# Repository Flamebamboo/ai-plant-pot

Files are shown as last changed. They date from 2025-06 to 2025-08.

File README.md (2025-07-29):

# SmartPlanter aka PixPlanter

This project is an emotive smart planter that plays an animation through its OLED screen depending on the conditions from the soil moisture, temperature & humidity sensors. It's also designed for portability with a 2000 MAH lipo battery and easy battery charging with USB type C from the ESP32 C6 from xiao. With this microcontroller it supports HomeKit and battery charging built it which i'm really excited about. The CAD design of this planter contains 2 seprate compartments. The inner pot and the outer pot. The inner pot has a snap fit design and drainage holes for water to safely exit throughout the pot. I will add an safety precautious by adding waterproof silicone for the 3d printed parts just in case if there will be leaks that can cause danger to the electronics on the housing of the outer case.

The reason I built this project is because I want my baby Monstera plant to be healthy on my desk! and it would also be a great addition as decoration too!

### Additionaly I've made some short vlogs on my Youtube channel and my brand new Instagram account
https://youtube.com/shorts/UrM3IPHNWJw?si=KoA7QMxdPpVGsMg
I'm definitely planning to create long form yt vid for this project when it's fully completed :)

> **⚠️ Warning:** I will be writing the firmware when the MCU arrive and I'm planning to create a Swift or React Native app for this smart planter to control and customise the planter features! :)) .
> 
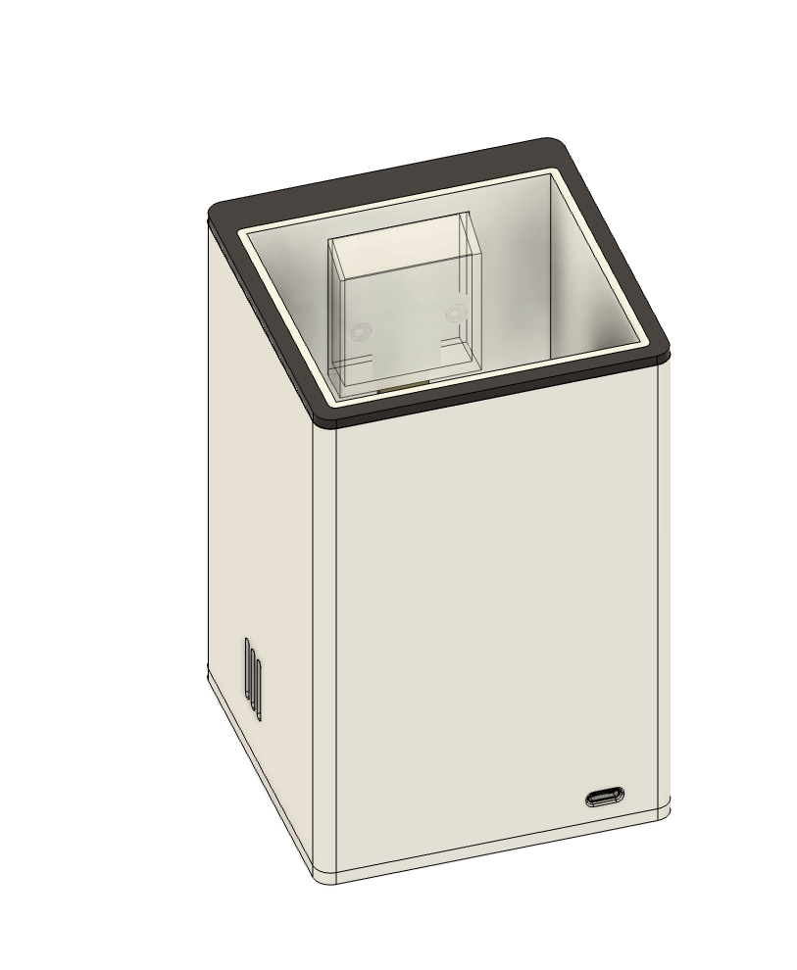
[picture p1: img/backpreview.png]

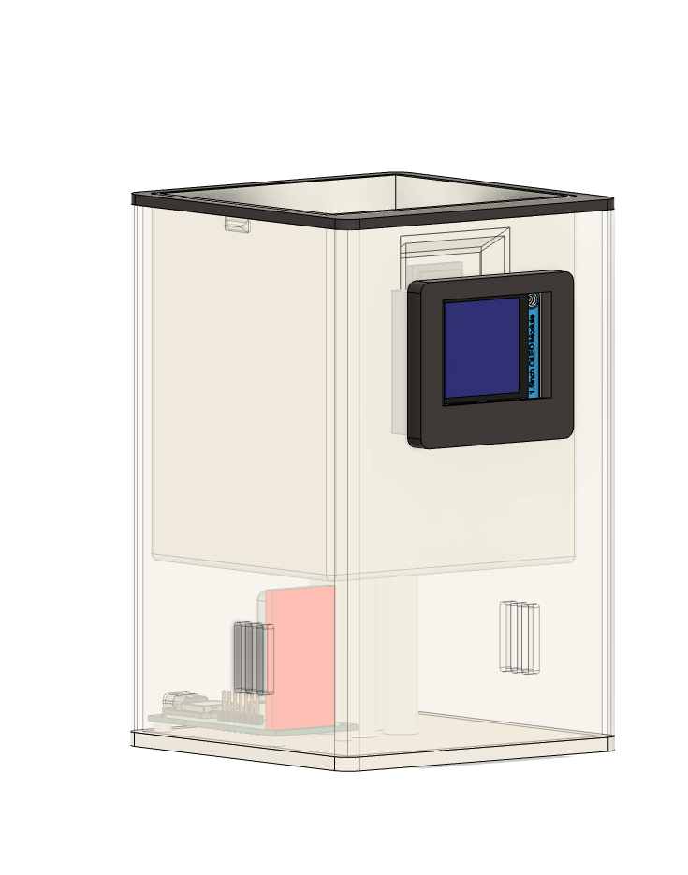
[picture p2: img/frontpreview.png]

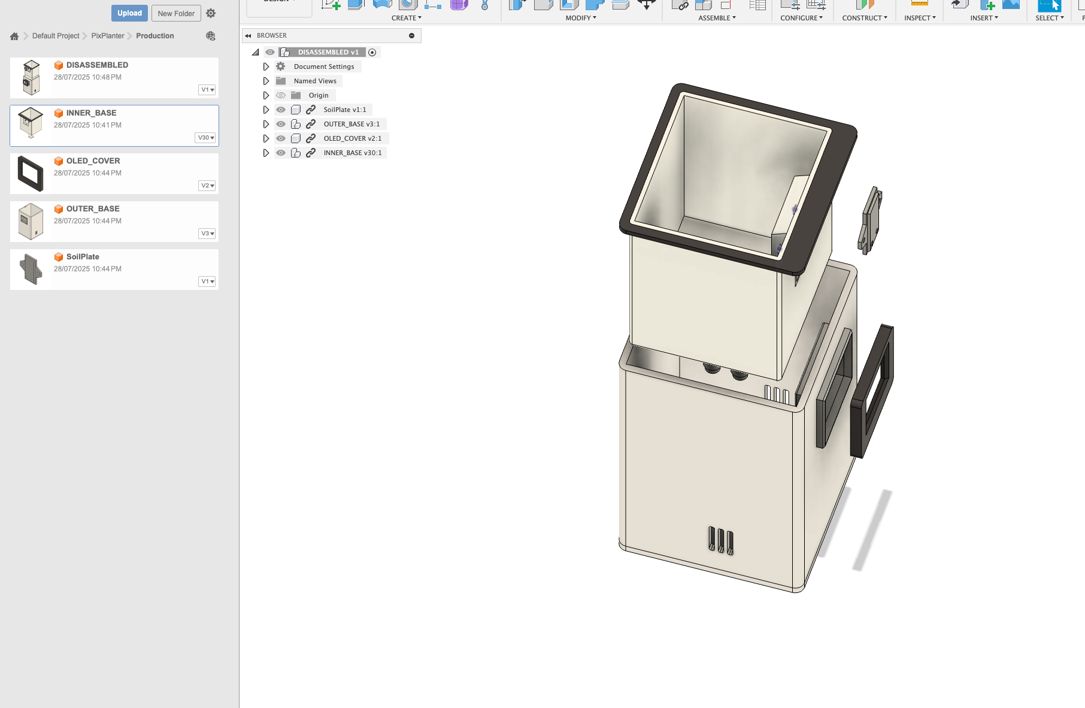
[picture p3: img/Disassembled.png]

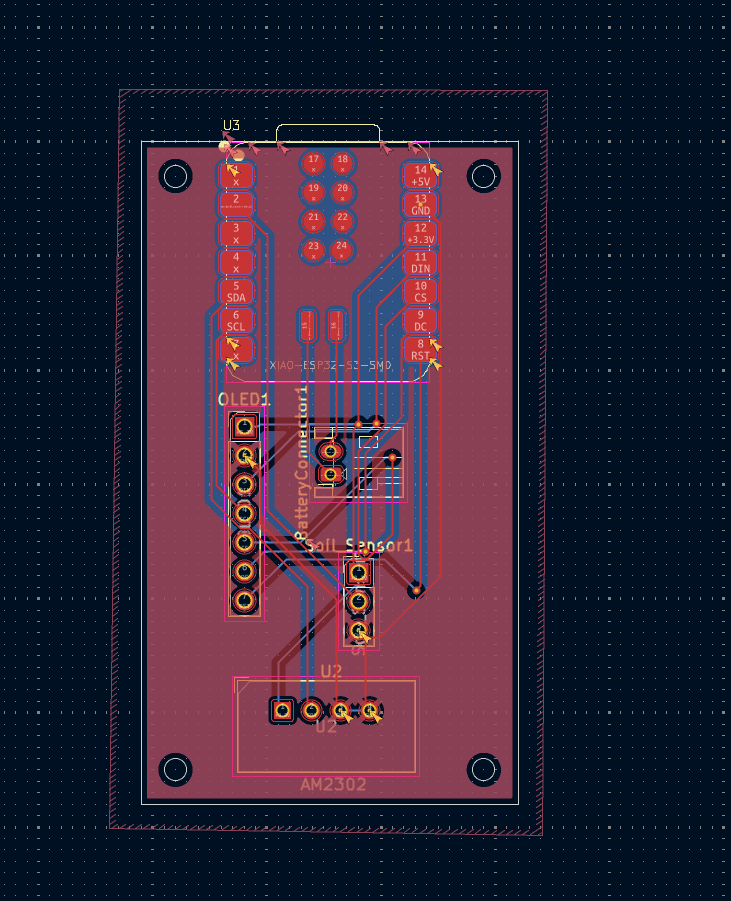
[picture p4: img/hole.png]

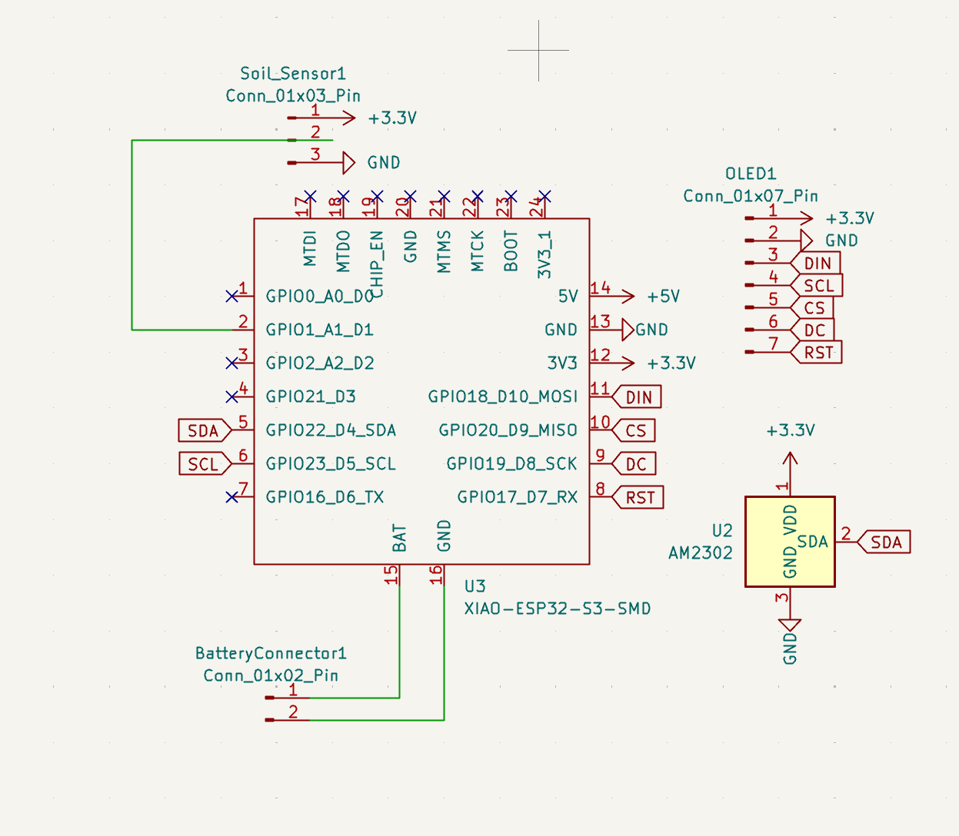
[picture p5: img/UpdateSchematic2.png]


## Bill of Materials (BOM)

| Component | Link | Price (USD) |
| --- | --- | --- |
| XIAO ESP32 C6 | [AliExpress](https://www.aliexpress.com/item/3256807155424151.html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) | $14.23 |
| 1.5 inch OLED display | [Waveshare](https://www.waveshare.com/product/displays/oled/oled-3/1.5inch-rgb-oled-module.html) | $16.59 |
| LIPO Battery 3.7V 2000mAH | [AliExpress](https://www.aliexpress.com/item/3256808031709894.html) | $3.86 |
| DHT22 Temperature and Humidity Sensor | [AliExpress](https://www.aliexpress.com/item/2251832573586959.html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) | $1.89 |
| Soil Sensor | [DigiKey](https://www.digikey.my/en/products/detail/adafruit-industries-llc/4026/9745252) | $7.50 |
| M2 × 8mm Screws | [AliExpress](https://www.aliexpress.com/item/2255800888609493.html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) | $1.59 |
| M2.6 × 4mm Screws | [AliExpress](https://www.aliexpress.com/item/2255800795894953.html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,scm-url:1007.22922.271278.0,pvid:9d1f35b8-b4ad-40c0-801f-28061212913c,tpp_buckets:668%232846%238115%232000&pdp_ext_f=%7B%22order%22%3A%222844%22%2C%22eval%22%3A%221%22%2C%22sceneId%22%3A%2212922%22%7D&pdp_npi=4%40dis%21USD%211.15%211.15%21%21%211.15%211.15%21%40214100f417536751956683208eb980%2110000013191635027%21rec%21US%216176438218%21X&spm=a2g0o.store_pc_home.smartLeaderboard_1182734993.4000982209705) | $1.29 |
| 2.54mm Pin Header Vertical (Soil moisture 2 pin) | [AliExpress](https://www.aliexpress.us/item/2255801012106911.html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) | $1.28 |
| 2.54mm Pin Header Vertical (OLED 7 pin) | [AliExpress](https://www.aliexpress.us/item/2255801012106911.html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) | $1.46 |
| JST PH 2.0mm Male Female Plug Jack Connector Cable 20 cm | [AliExpress](https://www.aliexpress.us/item/3256803204628036.html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) | $1.74 |
| **Total** | | **$51.43**  |

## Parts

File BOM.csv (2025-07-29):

Reference | Qty | Value | Footprint | Description | Link | Price
XIAO_ESP32_C6 | 1 | XIAO-ESP32-C6 | Library:XIAO-ESP32C6-SMD | XIAO ESP32 C6 | https://www.aliexpress.com/item/3256807155424151.html | 14.23
OLED_1.5IN | 1 | 1.5inch_RGB_OLED | Module:1.5inch_RGB_OLED | 1.5 inch OLED display | https://www.waveshare.com/product/displays/oled/oled-3/1.5inch-rgb-oled-module.html | 16.59
LIPO_BATT_2000mAh | 1 | LIPO_3.7V_2000mAh | Battery:LiPo_3.7V_2000mAh | LIPO Battery 3.7V 2000mAH | https://www.aliexpress.com/item/3256808031709894.html | 3.86
DHT22_AM2302 | 1 | AM2302 | Sensor:ASAIR_AM2302_P2.54mm_Vertical | DHT22 Temperature and Humidity Sensor | https://www.aliexpress.com/item/2251832573586959.html | 1.89
SOIL_SENSOR | 1 | Soil_Moisture_Sensor | Sensor:Soil_Moisture_3-Pin | Soil Sensor | https://www.digikey.my/en/products/detail/adafruit-industries-llc/4026/9745252 | 7.50
SCREW_M2_8MM | 1 | M2×8mm_Screw | Hardware:M2x8mm | M2 × 8mm Screws | https://www.aliexpress.com/item/2255800888609493.html | 1.59
SCREW_M2.6_4MM | 1 | M2.6×4mm_Screw | Hardware:M2.6x4mm | M2.6 × 4mm Screws | https://www.aliexpress.com/item/2255800795894953.html | 1.29
HDR_2PIN | 1 | PinHeader_1x02_P2.54mm | Connector_PinHeader_2.54mm:PinHeader_1x02_P2.54mm_Vertical | 2.54mm Pin Header Vertical (Soil moisture 2 pin) | https://www.aliexpress.us/item/2255801012106911.html | 1.28
HDR_7PIN | 1 | PinHeader_1x07_P2.54mm | Connector_PinHeader_2.54mm:PinHeader_1x07_P2.54mm_Vertical | 2.54mm Pin Header Vertical (OLED 7 pin) | https://www.aliexpress.us/item/2255801012106911.html | 1.46
JST_PH_CABLE | 1 | JST_PH_Cable_20cm | Connector:JST_PH_2.0mm | JST PH 2.0mm Male Female Plug Jack Connector Cable 20 cm | https://www.aliexpress.us/item/3256803204628036.html | 1.74

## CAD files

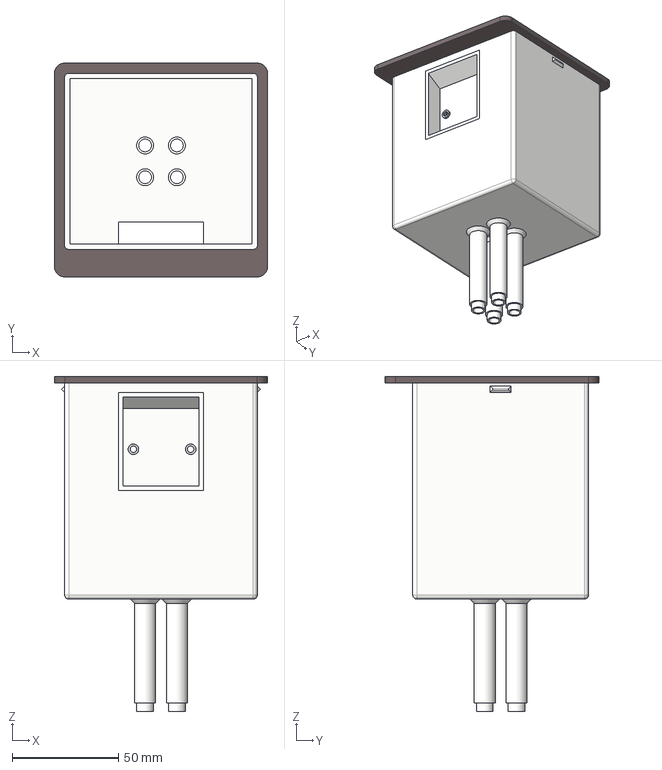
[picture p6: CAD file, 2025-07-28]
Production/CAD/INNER_BASE.step
100.7 x 100.8 x 158.0 mm
topofplanter

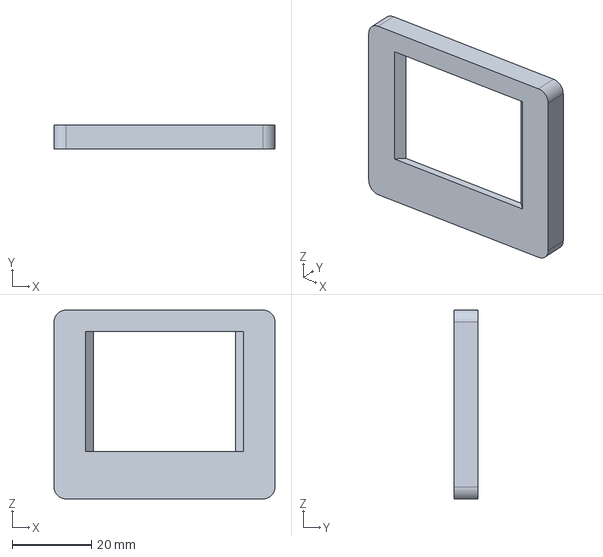
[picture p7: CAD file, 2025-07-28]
Production/CAD/OLED_COVER.step
55.8 x 6.00 x 47.7 mm

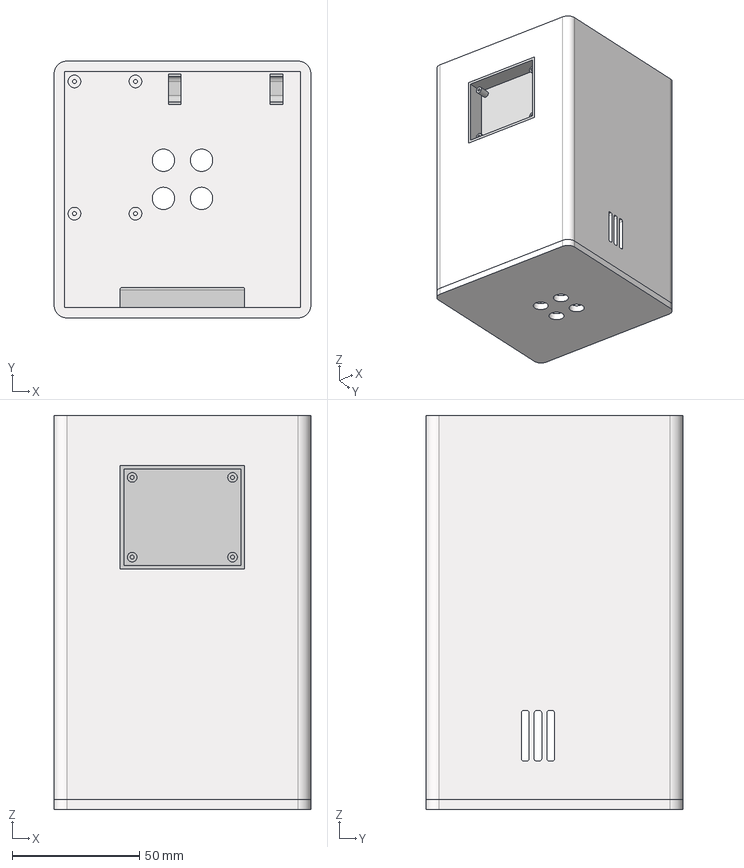
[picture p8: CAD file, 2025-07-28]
Production/CAD/OUTER_BASE.step
101.0 x 101.0 x 155.0 mm

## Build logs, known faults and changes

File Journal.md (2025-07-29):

---
title: "PixPlanter"
author: "Flamebamboo"
description: "smart planter with cute expressions! it has soil reading, surrounding temperature, motion, ambient light sensors that displays on a OLED screen! "
created_at: "2025-06-20"
---

## Total hours spent on design stage: 50.5 Hours

# June 20th: Gettin started with research

The first thing was asking a nerd friend who could give me some pointers how to get started on this project. This is my first custom project and I literally have no experience with electronics except making a MacroPad with a guide at hand. So the first thing I asked him was what parts I will be needing and he told me to do some research first on what features I will be needing for the planter. I moved on looking at some other commercial smart planter and this one is really cool called Ivy, it has temperature, soil moisture, ambient light, water level, touch and vibration?!? sensors. But as a noob I decided to keep it simple and cheap. so after some brainstorming I’m going with temperature, soil moisture, light, and motion sensors.

The parts that I’ve looked into are:

- [XIAO ESP32 S3](https://www.aliexpress.com/item/1005007084388623.html)
- [OLED RGB display](https://www.aliexpress.com/item/1005004794240558.html)
- [LIPO Battery 3.7V 2000mAH 103450](https://www.aliexpress.com/item/3256808031709894.html)
- [SHT30 Temperature And Humidity Sensor](https://www.adafruit.com/product/5064)
- [Adafruit STEMMA Soil Sensor - I2C Capacitive Moisture Sensor - JST PH 2mm](https://www.adafruit.com/product/4026)
- [Adafruit BH1750 Light Sensor - STEMMA QT / Qwiic](https://www.adafruit.com/product/4681)

**Estimated Costs (USD):**

- XIAO ESP32 S3: $6.90
- OLED RGB display: $10.10
- LIPO Battery 3.7V 1500mAH 103048: $4.70
- SHT30 Temperature And Humidity Sensor: $8.95
- Adafruit STEMMA Soil Sensor: $7.50
- Adafruit BH1750 Light Sensor: $4.50

My project roadmap ->
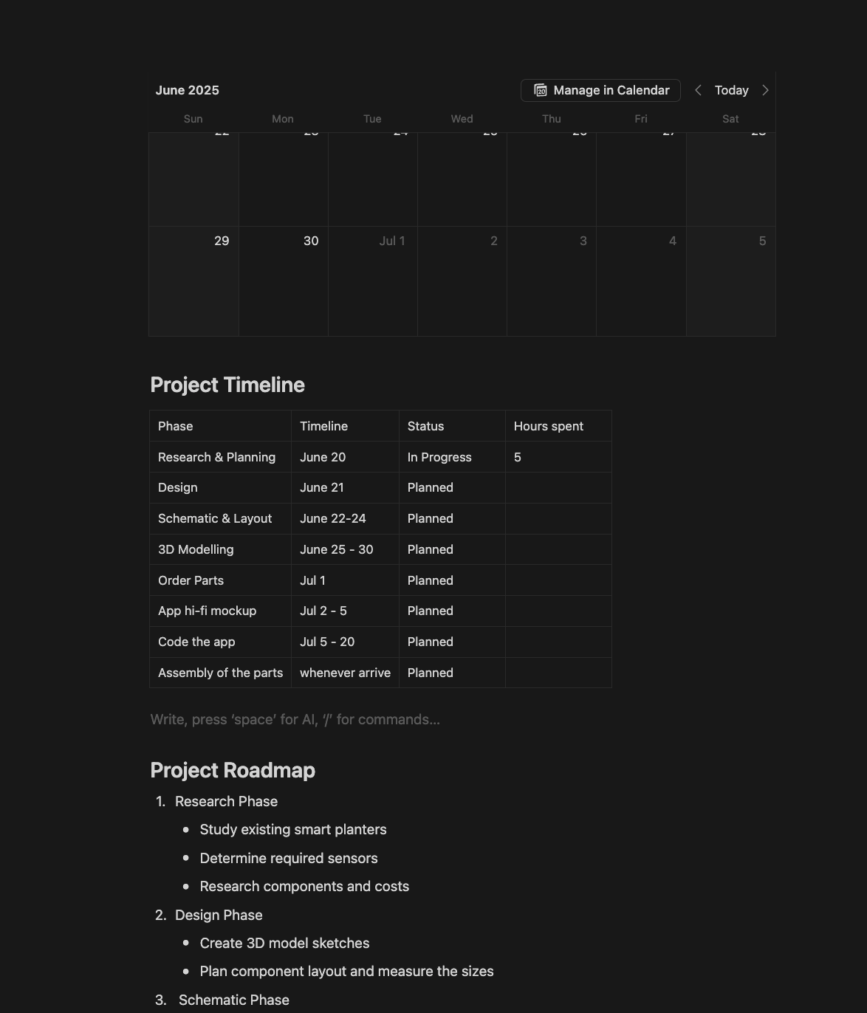
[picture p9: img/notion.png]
Roadmap


I also made some prototype sketches here.
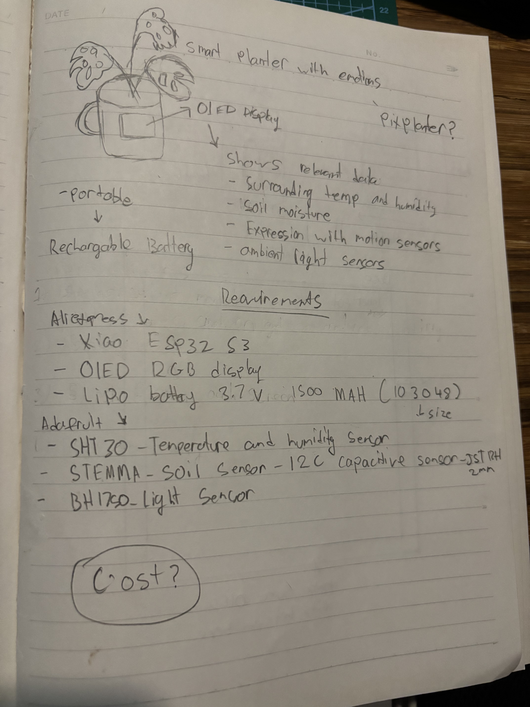
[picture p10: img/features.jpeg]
Prototype Sketch 1

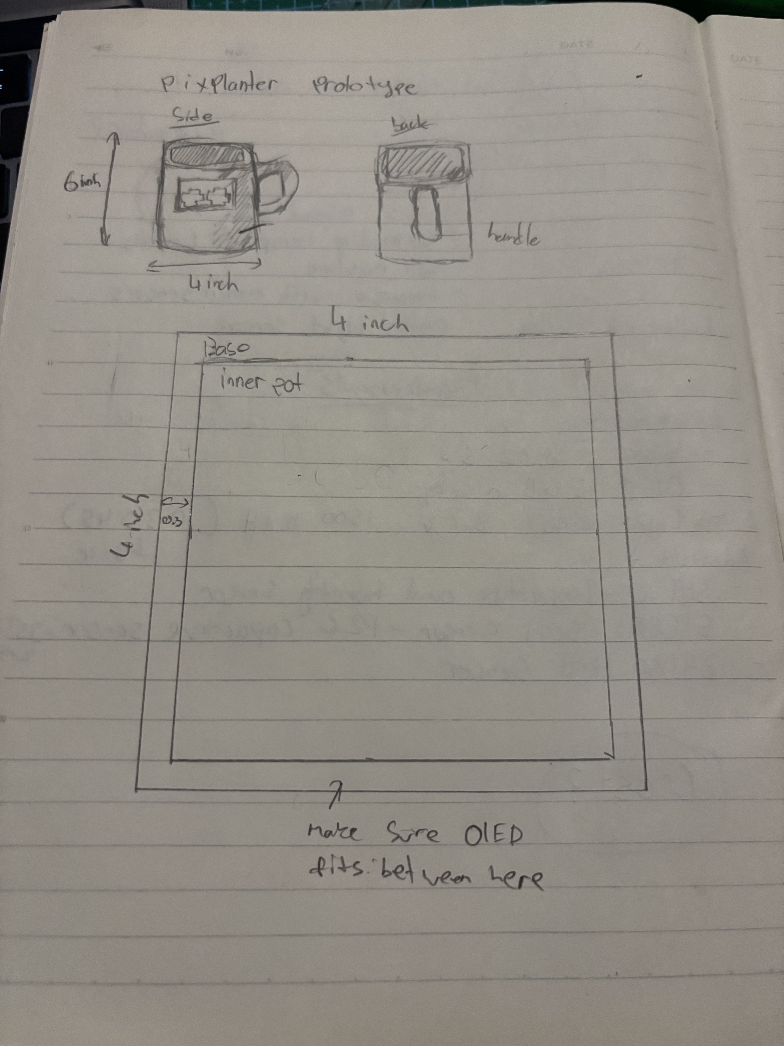
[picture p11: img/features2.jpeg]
Prototype Sketch 2

**Total time spent: 5.5h**

# June 21th: Understanding more about the parts + design schematics

I just found out that to charge the battery effectively it will require a battery charger module called TP4056. TP4056 has two different variations with protection IC and without protection. Without protection IC it only protects overcharge, with protection IC it protects overdischarge and over current protection.

I imported the OPL libary for my XIAO ESP32 S3 into KICad and I also added some other pins and batttery module and started wiring for it.. Except I have no clue how to do this....

After some research I found out that the battery can directly connect to XIAO ESP32 from the -BAT and +BAT. I intend to change the ESP32 S3 to C6 since I need an MCU that supports Thread which then allows me to integrate with IOS nicely.

- XIAO ESP32 S3 -> XIAO ESP32 C6 (Thread support )
- LIPO Battery 3.7V 1500mAH 103048 -> LIPO Battery 3.7V 2000mAH (longer battery life)
- SHT30 Temperature And Humidity Sensor -> SHT40 Temperature And Humidity Sensor (apparently better and $2 cheaper)

I have no idea if this is correct or what... 😞
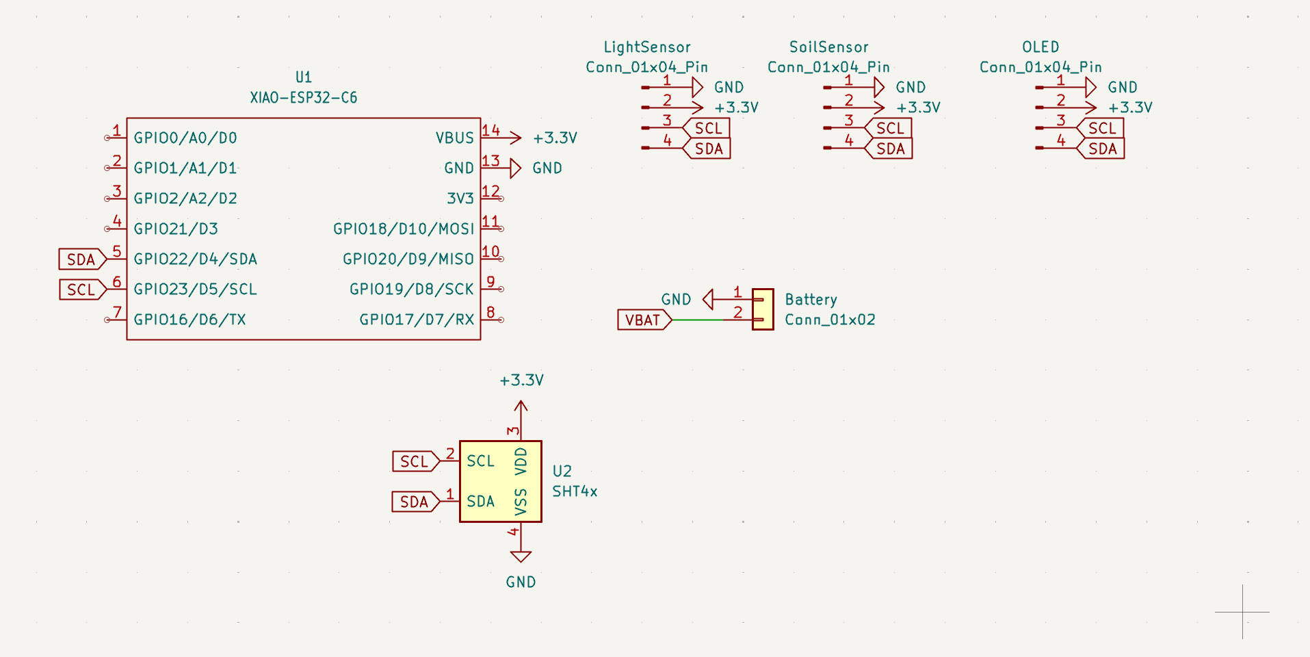
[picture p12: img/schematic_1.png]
schematic_1


**Total time spent: 3.5h**

# June 22th: Applying footprints

Oh boy... This one was SUPER SUPER confusing for me. I made some changes for the parts to places more "trusted" with well documented parts instead of going to AliExp, the parts like 1.5 inch OLED from waveshare raises the prices abit (hope its okay for Hack Club) because as a beginner who barely have any electronics knowledge I dont understand what schematics symbols to add, what in the world is footprints, and what these parts footprints is. I read the docs aswell as back and fourth chatting with co pilot to assist me making sure that I assigned the correct footprint for each parts.

I hope this is correct ;-;
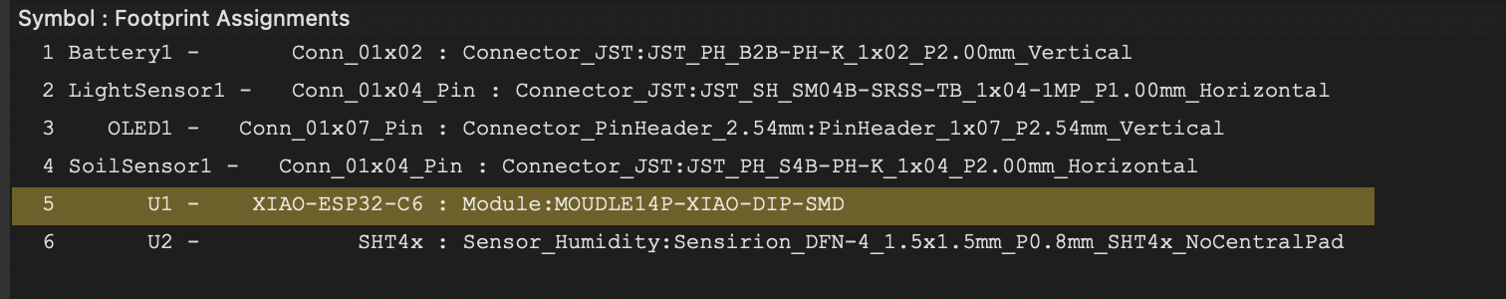
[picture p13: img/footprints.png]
footprints


me chatting with copilot for an hour? xD
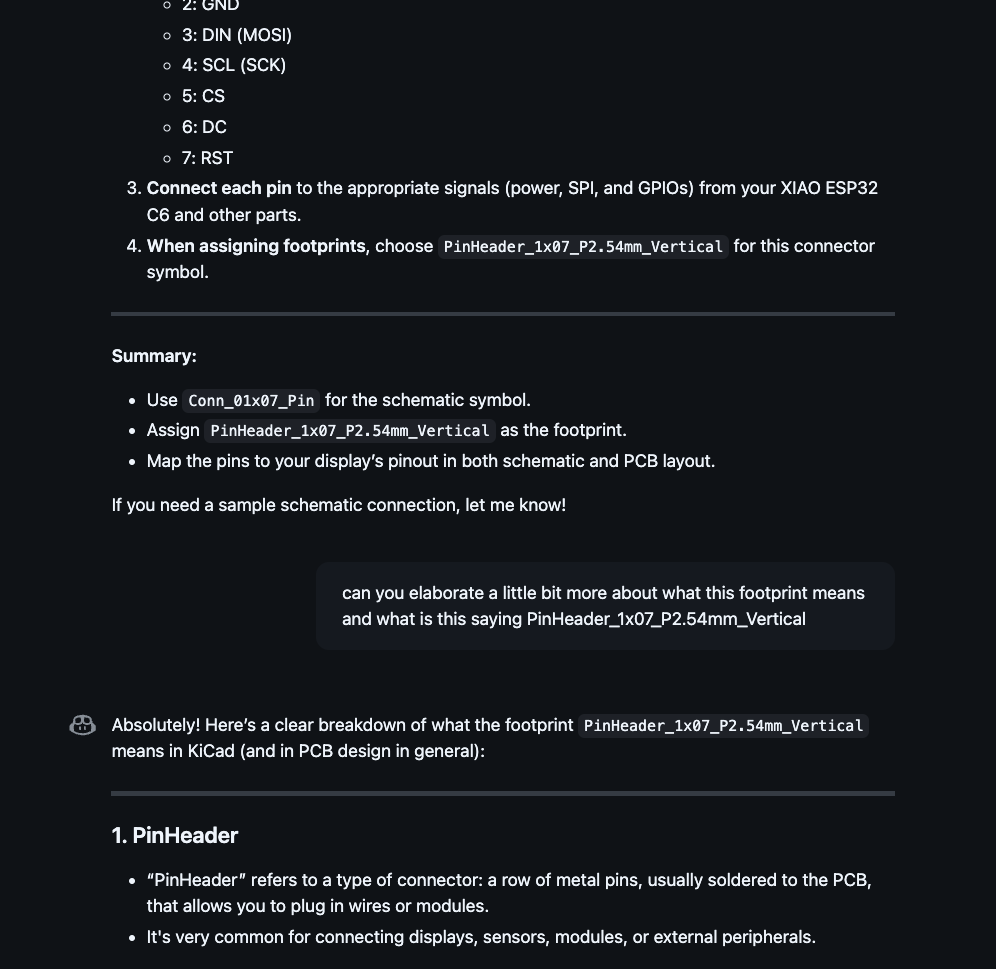
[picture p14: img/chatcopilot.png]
chatcopilot

**Total time spent: 2h**

# June 25th: Research Routing the PCB

12AM - 2:16 AM

I finally got into routing the PCB. After going through the documentations for the esp32 I decided to remove the 1x2 connecting pin for the battery because apparently I wont be needing the PH2.0 plug rather just cutting it off and directly solder to the XIAO smd pads! (The MCU schematic does not show 15 and 16 pins for me to connect the wire too so I could'nt figure out how to use the connectors ;-;)

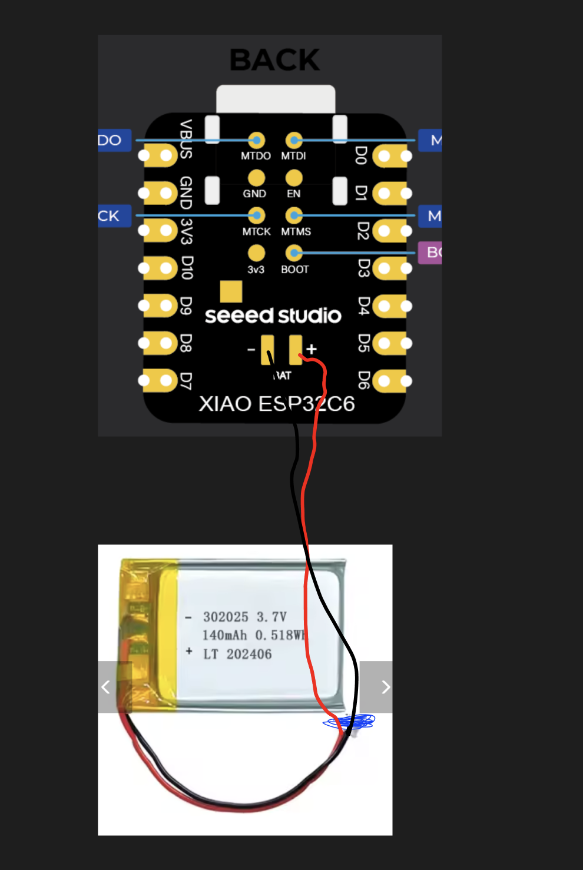
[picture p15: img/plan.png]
Plan


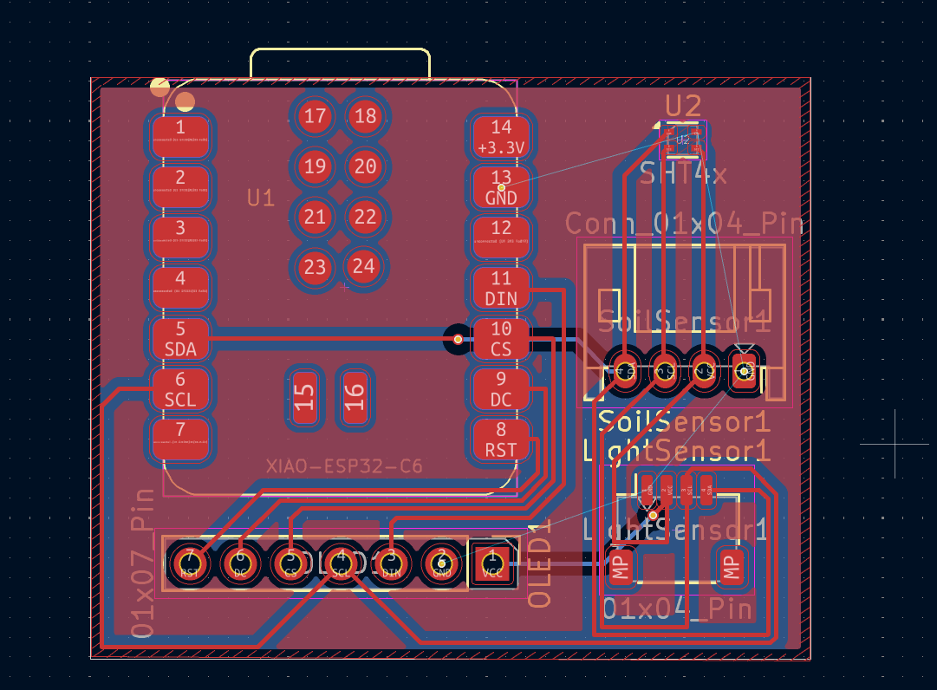
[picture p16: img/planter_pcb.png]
PCB


I also used ground fill for the first time :) hope I did it right

**Total time spent: 2h**

# June 27th: I was filming a vlog for day 1:

Youtube [YouTube Short](https://youtube.com/shorts/ty__Sh_dJmw?si=zp3qn9vOzwV2mKUi)
Scripting, Filming, ediitng took a while and I cant remember the time exactly...

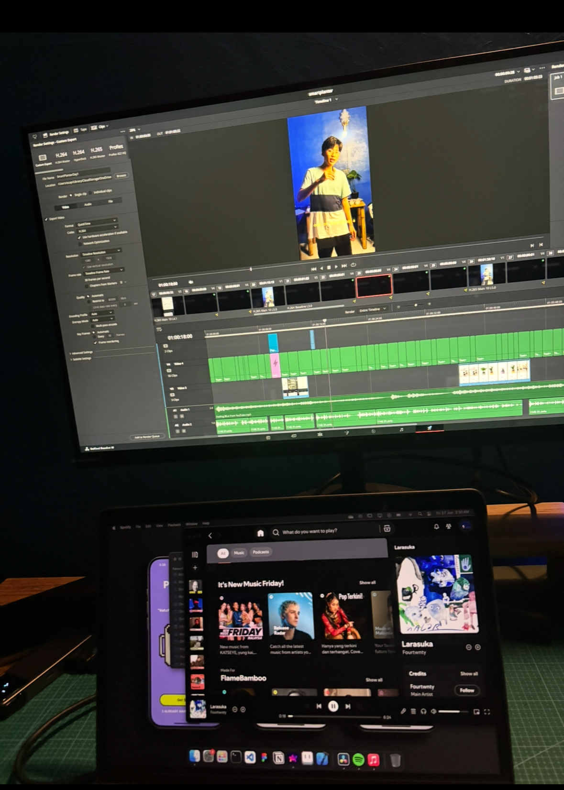
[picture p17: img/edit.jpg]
edit


**Total Time: Uncounted for this project**

# June 28th: allocating components and 3D sketch

Researching on the ideal size of the pot thickness, the recomendded volume for my Monsterra plant and yeah...

I started sketching the base of the planter, taking account into the water drainage and where the electronic components will go

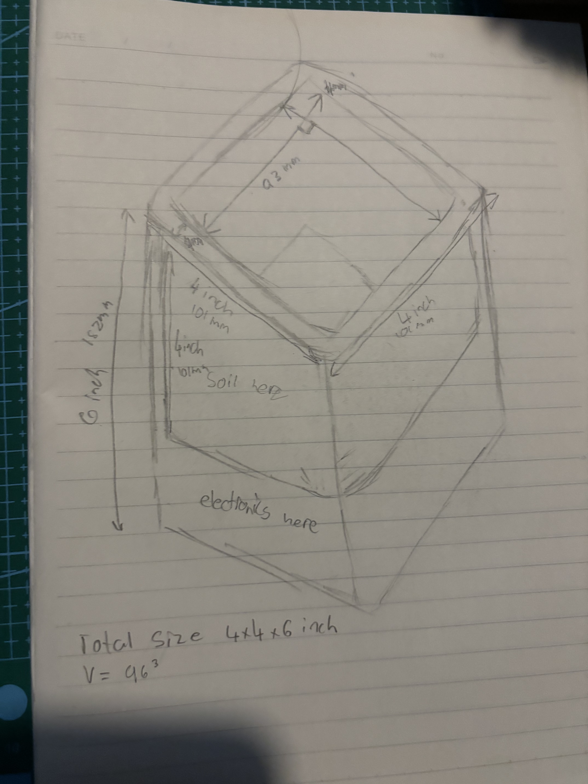
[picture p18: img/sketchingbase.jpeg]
Sketch


The outer dimensions for this planter will be 101x101x182mm and the inner case (inner pot where the soil and plant will go) will be 93x93x101. the empty space at the bottom as shown in the sketch will be allocated for the electrical components aswell as a funnel and holes for the water to flow out.

**Total time spent: 3h**

# June 29th: Fusion 3D Modelling

I stated jumping into fusion and start to create the outer and inner case. I also make sure to add a cutout for the OLED to sit in... But then I just realised I need to make the gaps bigger and make the OLED casing more compact and more integrated.

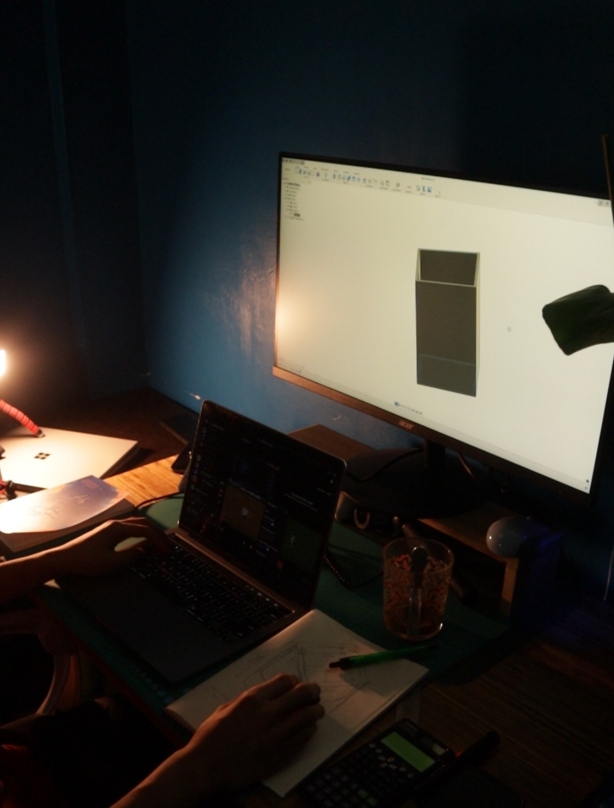
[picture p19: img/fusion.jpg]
Model


**Total time spent: 4h**

# July 1: Fusion 3D Modelling the enclosure for OLED

This got me burntout...

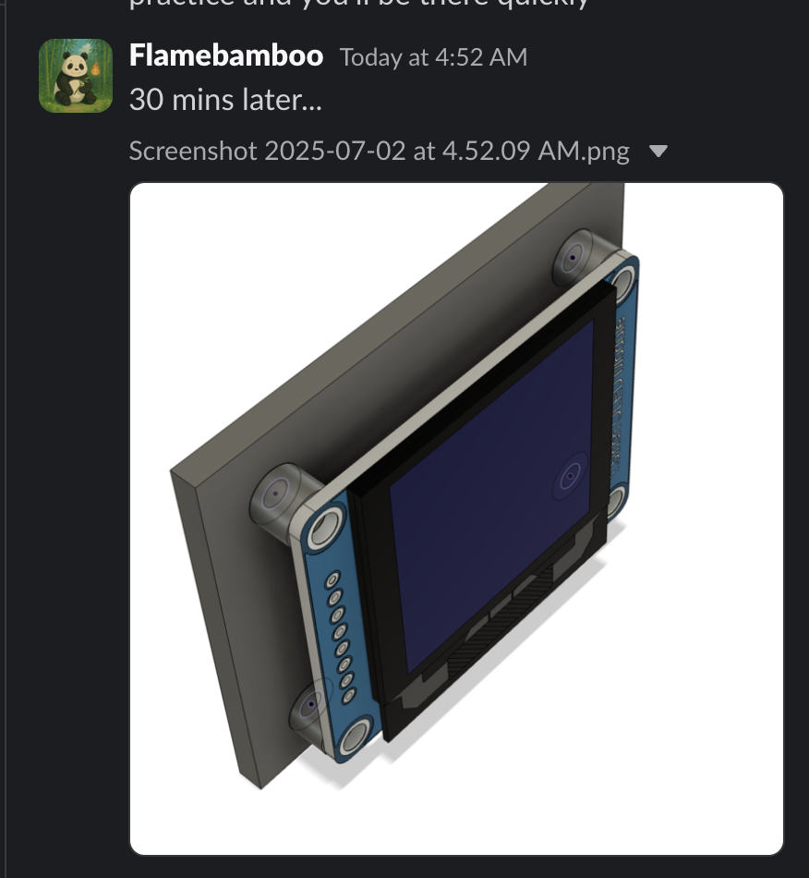
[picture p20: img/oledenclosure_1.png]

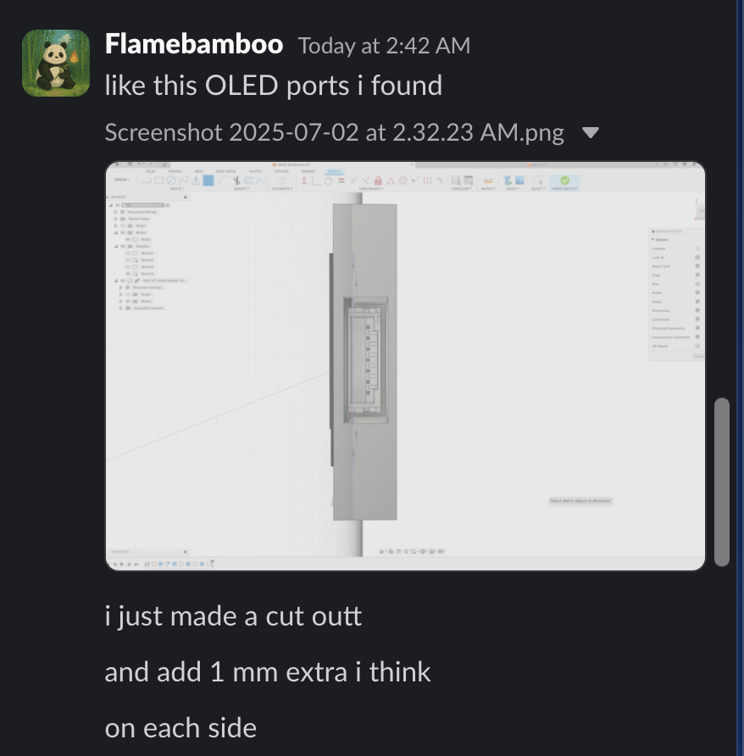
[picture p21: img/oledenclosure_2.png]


I spent 11pm - 5:30 AM trying to figure out how to use these new tools i've never used before such as project tools, offsets.

Then I had to figure out how to somehow attach the enclosure to the base by joining it (maybe?)...

I kept reiterating and doing the same thing trying to figure it out.

I ended up revamping and start from scratch a ton of times!

still no progress at this point.

**Total time spent: 6h 30m**

# July 2: Released day 2 video

I filmed, edited a content for day 2 which was for the work I did back in June 21st

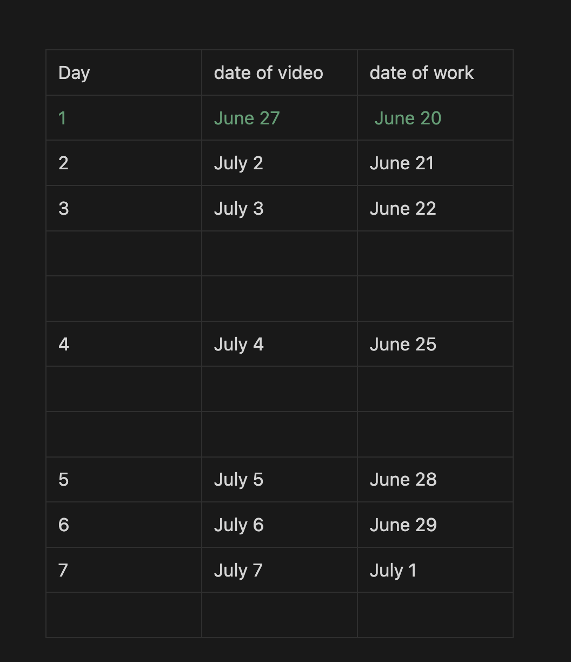
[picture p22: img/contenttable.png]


here's the video [youtube](https://youtube.com/shorts/amHQEBcOXe8?si=QgyBYHKR3km967V8), [instagram](https://www.instagram.com/reel/DLnImsxTx7t/)

**Total Time: Uncounted for this project**

# July 19:

I have given up for a while because I was burntout from using Fusion, but a burst of motivation finally came back and it is time. I completed the enclosure with snap fit perfectly. The enclosure is seperated with back, middle, front. "Back" is combined with the main base body and "Mid" is combined to "Back" with some chamfer for easy fit. The "Front" Part is standalone with a 0.4mm of fit deviation that can later be attached directly from outside the main base.



**Total time spent: 3h**

# July 20:

Continue working on the inner pot with 5 drainage holes.



**Total time spent: 1h**

# July 23:

Today I worked on redesigning the edge cut for the pcb to fit the enclosure base nicely
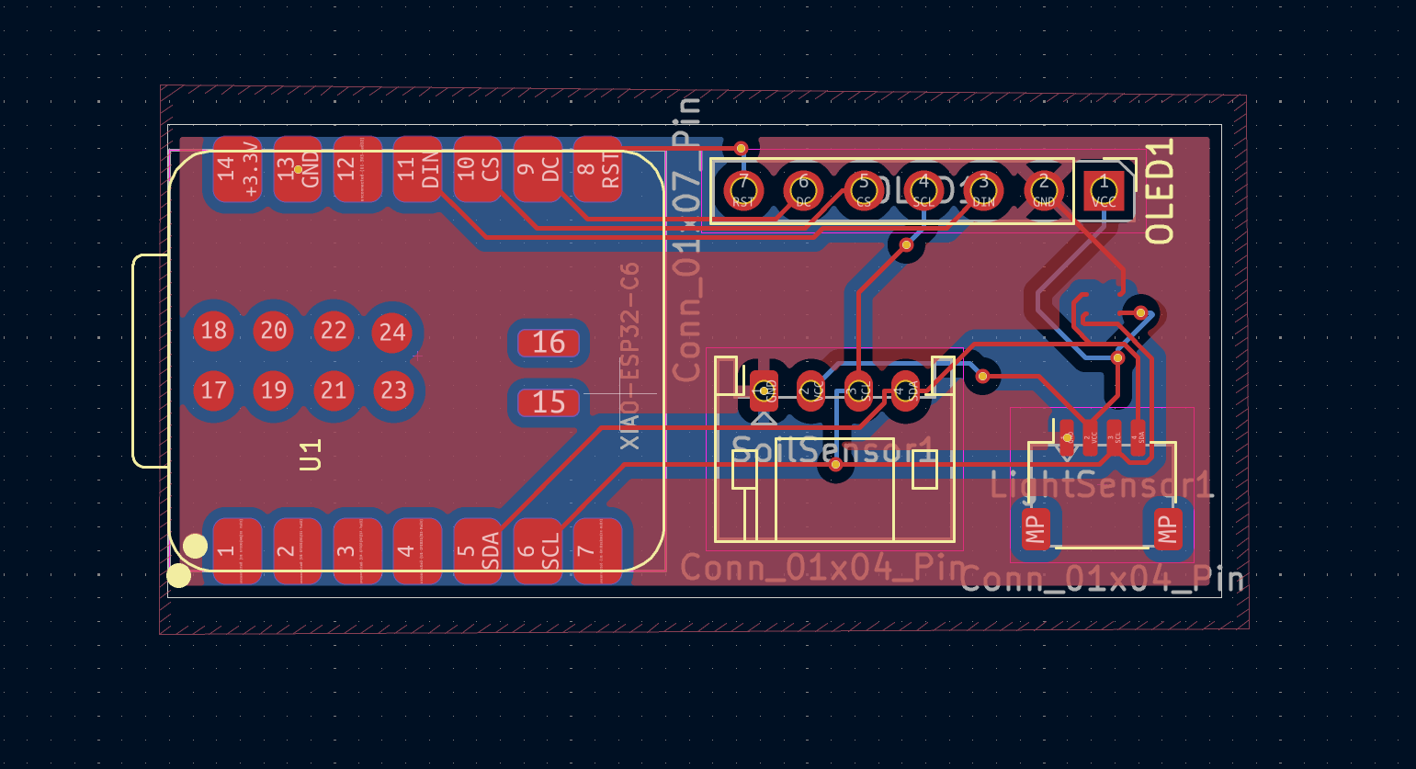
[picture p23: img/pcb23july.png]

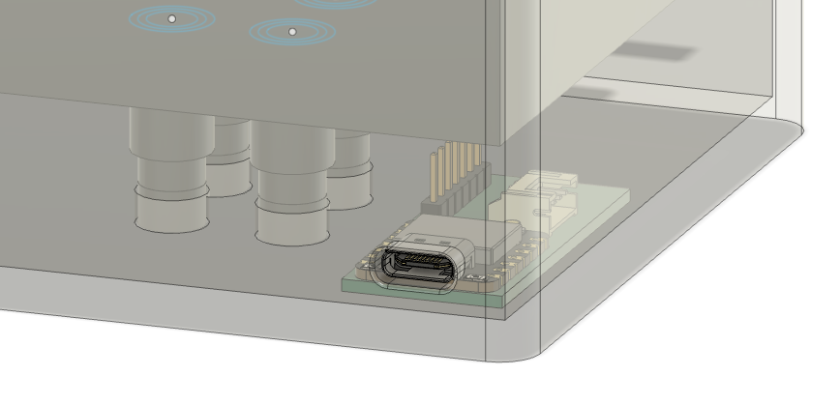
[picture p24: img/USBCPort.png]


**Total time spent: 30m**

# July 26:

Today I made changes to the BOM because I removed some sensors and changed it to be more cost effective.

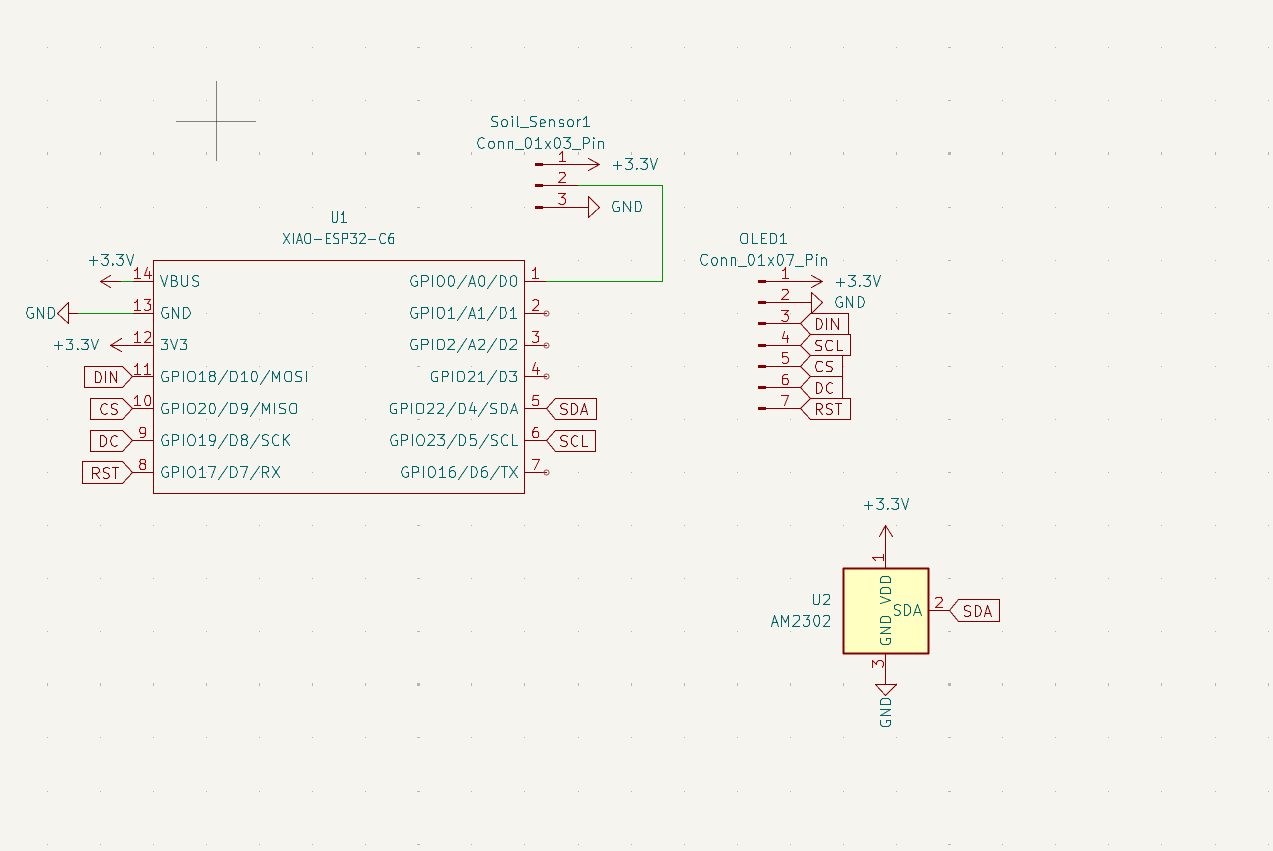
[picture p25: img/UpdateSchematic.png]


I finally realised that I've used the wrong symbols in the schematic for Xiao ESP32 C6 it should be the SMD one so I have the pins for BAT and GND!!!! now I can finally connect the ph 2.0 connector

**Total time spent: 2h**

# July 27:

This is probably the 5th time making changes to the PCB:
I needed mounting holes to screw on the pcb to keep it in place at the bottom of the housing.
The sizes for the mounting holes on the PCB's are 3mm and 3.5mm as via diameter.


I also added M2 \* 8 self tapping screws for my OLED mounting -I made some changes to the hole diameter to 1.6mm instead of 2.7
So here's the update to the OLED Enclosure
Boss outer diameter: 3.8mm
Pilot hole diameter: 1.6mm  
Boss height: 6.54mm

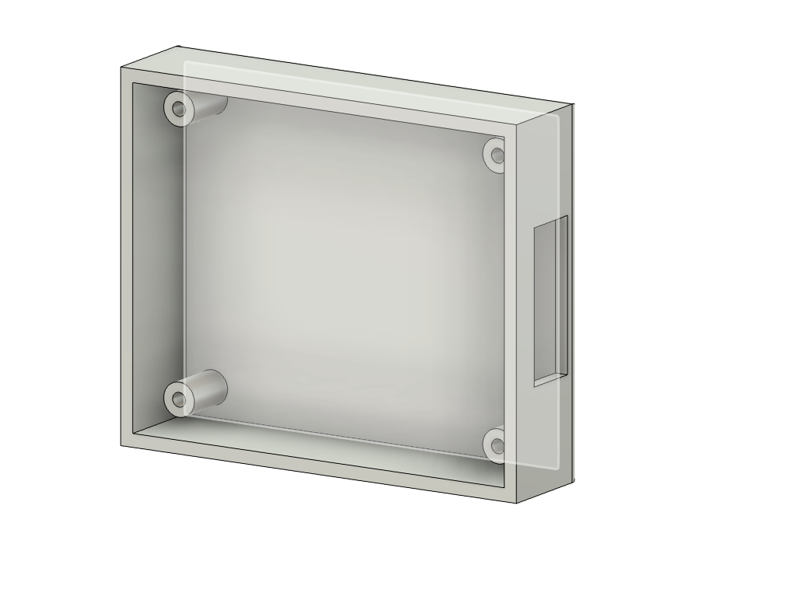
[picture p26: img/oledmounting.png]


I also designed a venting holes for proper airflow so that the DHT22 sensors can read the temperature and humidity accurately.

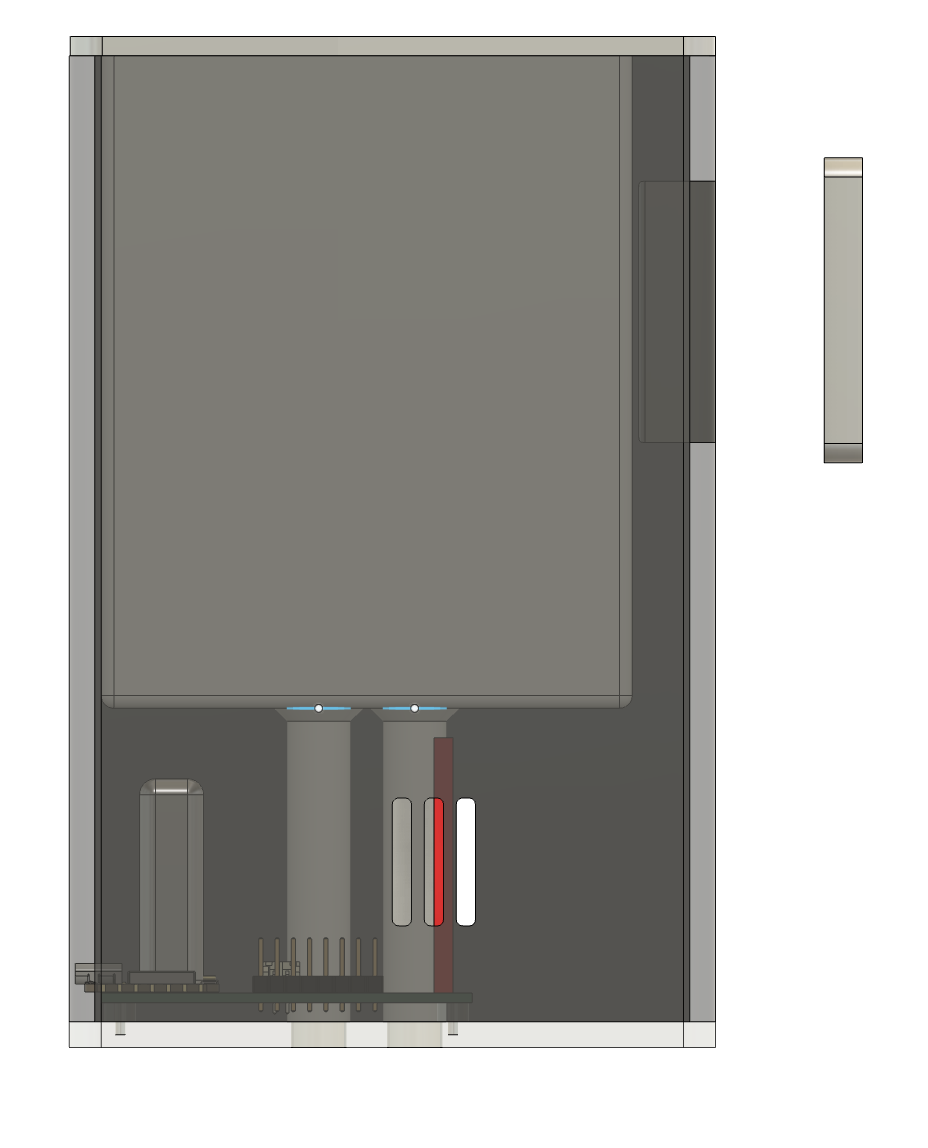
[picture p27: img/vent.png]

**Total time spent: 5h**

# July 28:

TODO:

DONE: Create battery holder in the housing.
DONE: Create a soild sensor hole from the bottom to insert it

- Final design polish model, BOM & github repo etc

Finish? Hopefully

This morning I designed the compartment to attach soil sensor right at the inner pot.
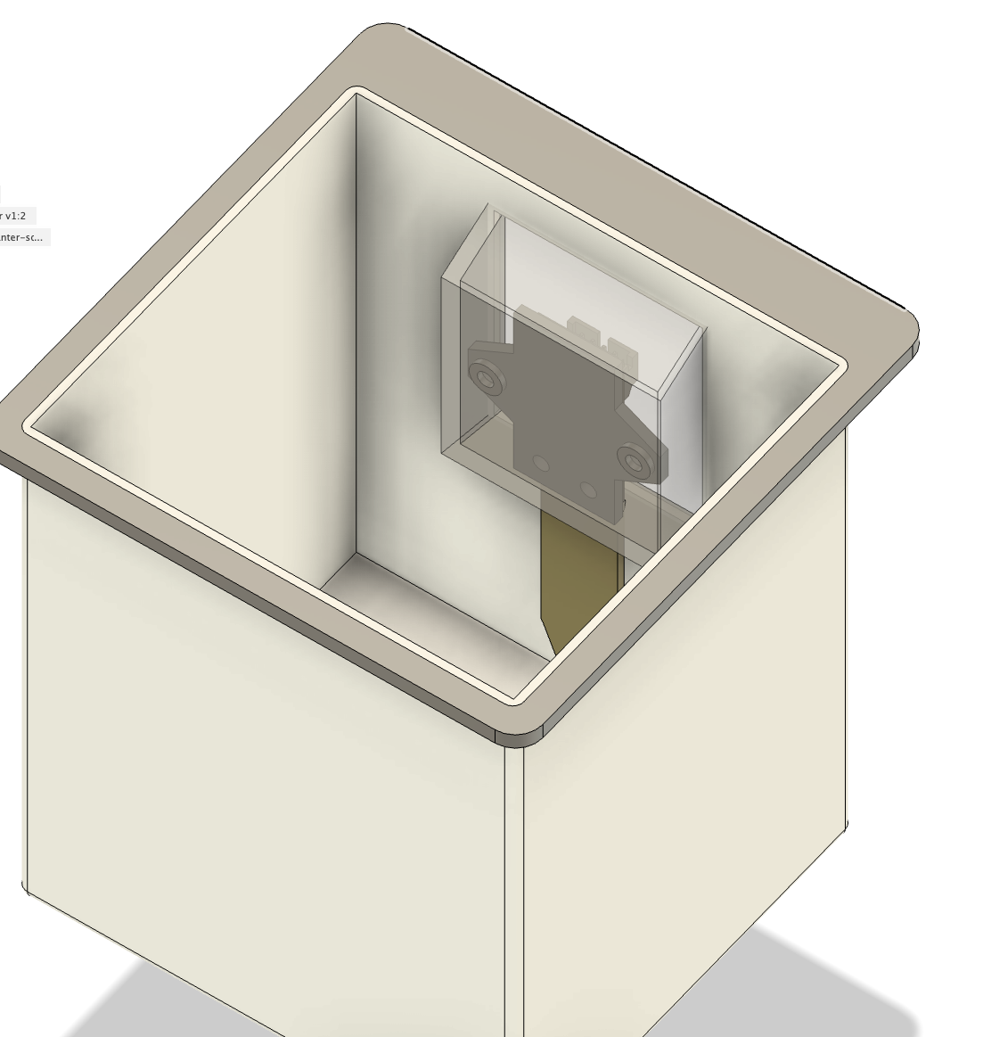
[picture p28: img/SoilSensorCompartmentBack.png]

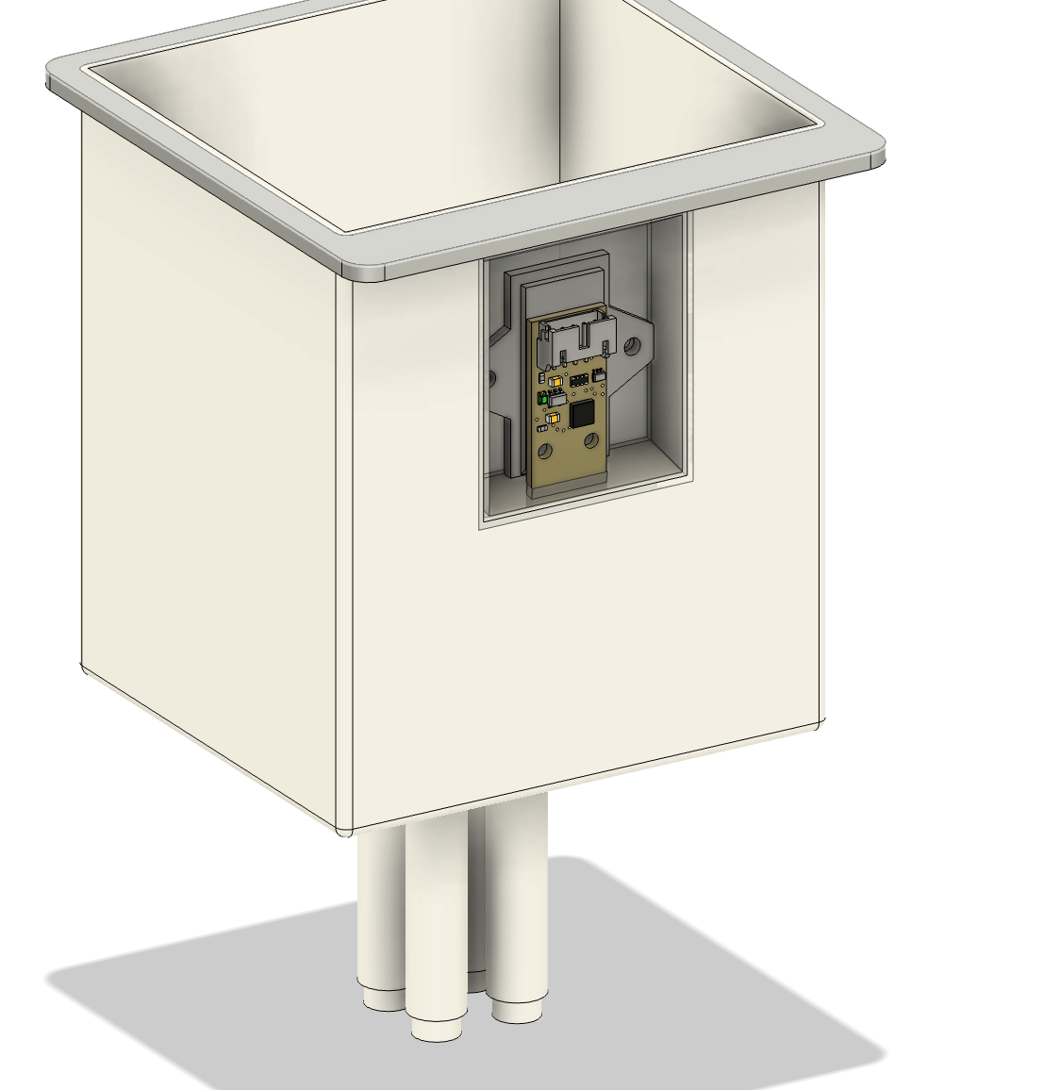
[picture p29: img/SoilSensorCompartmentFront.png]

The soil sensor plate are inspired by some smart planter design I found
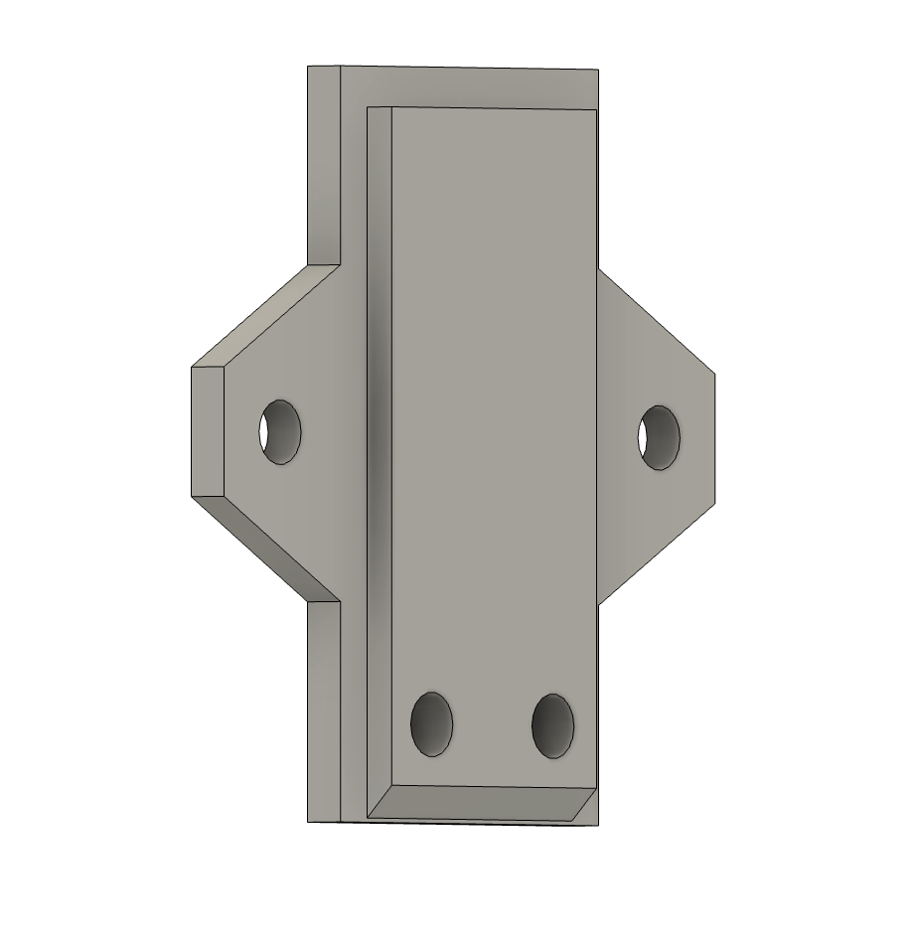
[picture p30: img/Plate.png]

The holes on the soil sensor are nicely projected to the Plate.

The screws to attach these are M2.6 \* 4mm.

This afternoon I added some snap fit features for the base and inner pot to attach

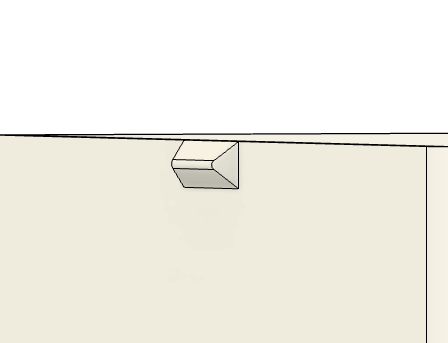
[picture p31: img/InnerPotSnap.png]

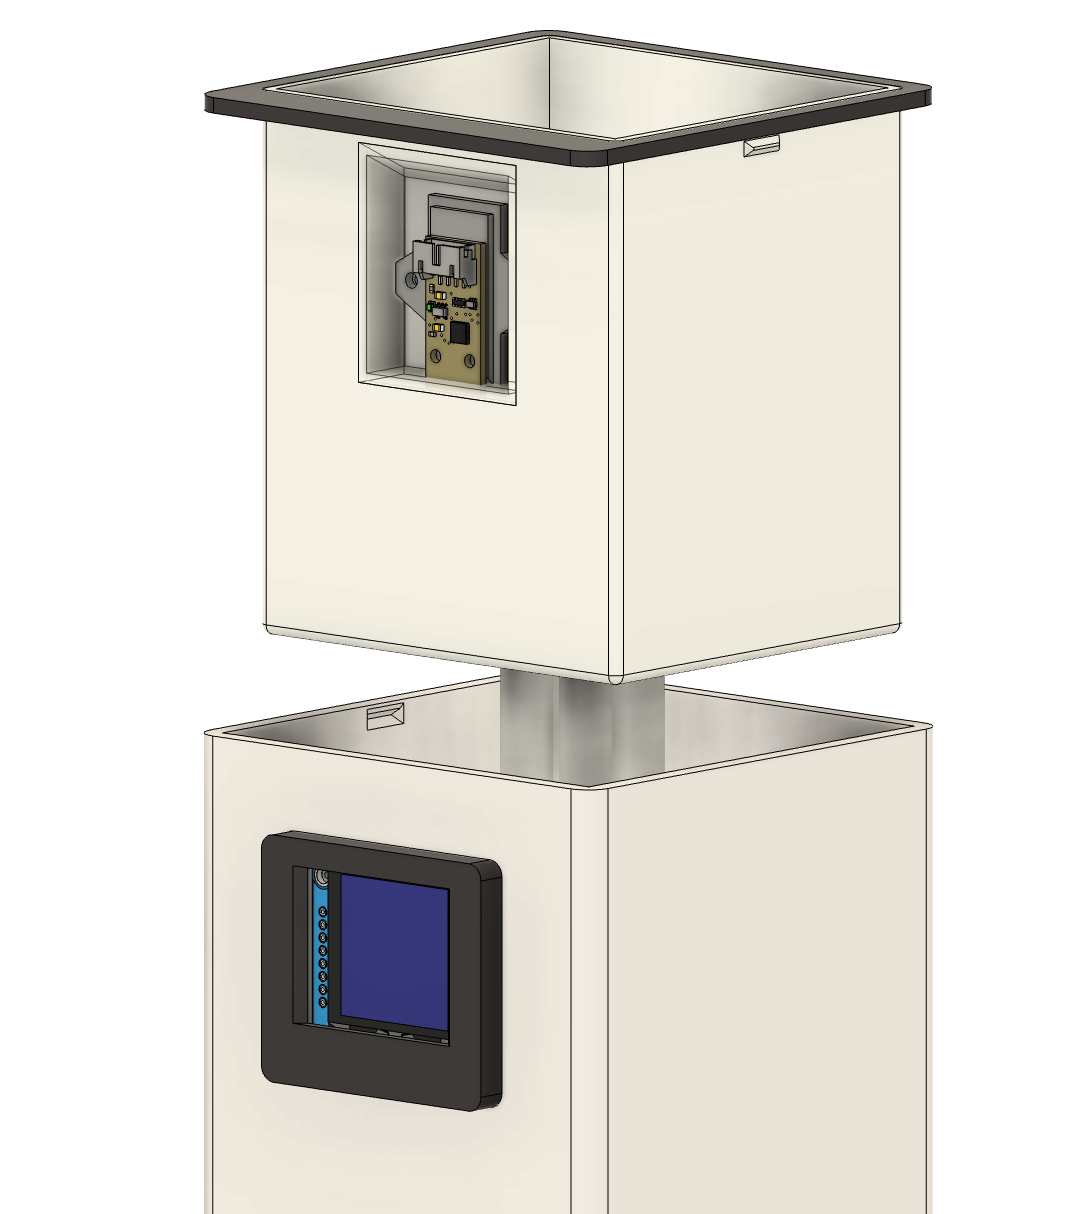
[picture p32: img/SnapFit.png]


- It is 10mmx2mmx3mm in dimension with a taper angle of 45 degrees.
- The snap fit on the base has a 0.2mm offset in outer dimension to make it slightly bigger and easier to slide in. It also has a 0.6mm chamfer on the top side.

Created a simple battery holder
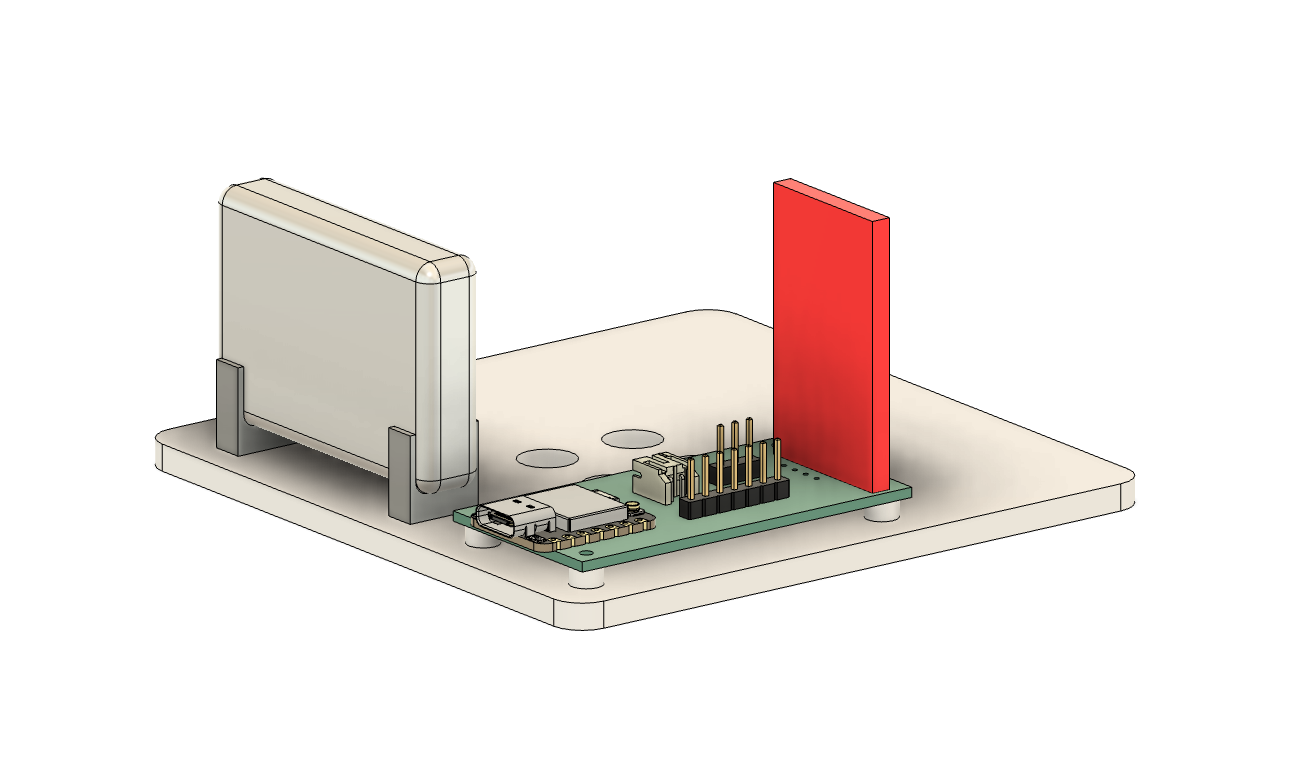
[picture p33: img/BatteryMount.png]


Here is the final preview of this project!



There is 4 seperate CAD files to be printed:

1. The outer enclosure
2. The inner pot
3. Soil plate
4. OLED plate



**Total time spent: 7h**

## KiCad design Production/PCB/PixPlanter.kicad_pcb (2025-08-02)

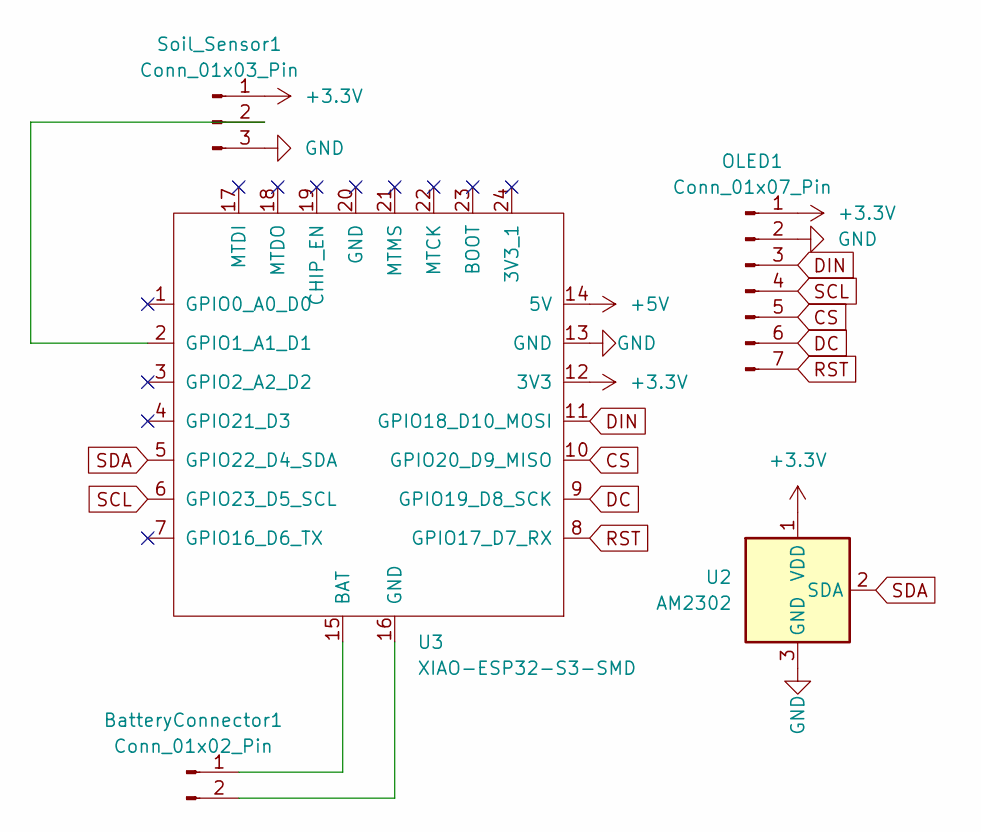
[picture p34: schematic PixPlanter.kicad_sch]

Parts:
BatteryConnector1: Conn_01x02_Pin; JST_PH_S2B-PH-K_1x02_P2.00mm_Horizontal
OLED1: Conn_01x07_Pin; PinHeader_1x07_P2.54mm_Vertical
Soil_Sensor1: Conn_01x03_Pin; PinHeader_1x03_P2.54mm_Vertical
U2: AM2302; ASAIR_AM2302_P2.54mm_Vertical
U3: XIAO-ESP32-S3-SMD; XIAO-ESP32C6-SMD

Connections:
+3.3V: OLED1.1, Soil_Sensor1.1, U2.1 (VDD), U3.12 (3V3)
+5V: U3.14 (5V)
CS: OLED1.5, U3.10 (GPIO20_D9_MISO)
DC: OLED1.6, U3.9 (GPIO19_D8_SCK)
DIN: OLED1.3, U3.11 (GPIO18_D10_MOSI)
GND: OLED1.2, Soil_Sensor1.3, U2.3 (GND), U2.4 (GND), U3.13 (GND)
unnamed: BatteryConnector1.1, U3.15 (BAT)
unnamed: BatteryConnector1.2, U3.16 (GND)
unnamed: Soil_Sensor1.2, U3.2 (GPIO1_A1_D1)
RST: OLED1.7, U3.8 (GPIO17_D7_RX)
SCL: OLED1.4, U3.6 (GPIO23_D5_SCL)
SDA: U2.2 (SDA), U3.5 (GPIO22_D4_SDA)

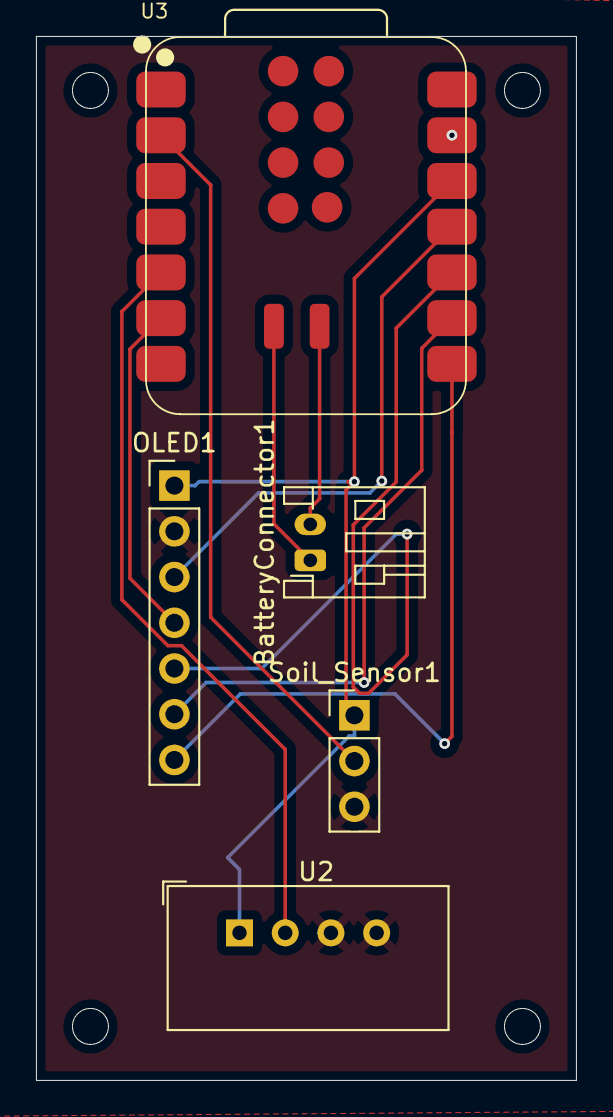
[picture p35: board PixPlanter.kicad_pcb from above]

Board: 2 copper layers, 30.0 x 58.0 mm, 5 parts (0 on the bottom side), 11 nets.

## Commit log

2025-06-22 added BOM into readme
2025-07-23 base enclosure image
2025-07-26 removed light sensors
2025-07-26 Reduce sensor cost + update links
2025-07-28 BOM table
2025-07-28 Imported CAD files in production folder
    [INNER_BASE.step, OLED_COVER.step, OUTER_BASE.step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]
2025-07-28 refine my journal and added gerbes for PCB
2025-07-29 added BOM and readme of short description of this project
    [BOM.csv]
2025-07-29 update BOM with AI
    [BOM.csv]
2025-07-29 added Assembled step CAD
2025-08-02 Source file -rereview
    mistake on my end :(
    [PixPlanter.kicad_pcb, PixPlanter.kicad_sch]
